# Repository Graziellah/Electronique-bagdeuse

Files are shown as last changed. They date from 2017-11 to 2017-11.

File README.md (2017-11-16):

# 42-electrons

Electronic project, group repertory

## Project specifications list

- [ ] A project name

- [ ] A project introduction

- [ ] A block diagram who's showing all the needed elements
    - [ ] At center the PIC32 chip
    - [ ] On borders the connectors
    - [ ] Between them, what is connected to what, how, and with what protocol

- [ ] A previsionnal manual who explain how to use
    - [ ] A final user must know how to use the final product

- [ ] Product specifications
    - [ ] Showing module (2 lines * 16 chars)
    - [ ] Memory
    - [ ] ...

- [ ] Functionnal calculations who explains the technical choices

- [ ] A list of protocols who will be used
    - [ ] How they will be used
    - [ ] How are they usefull
    - [ ] RFC
    - [ ] Implementation
    - [ ] Limitations

- [ ] A bill of materials
    - [ ] Components list
        - [ ] Compatibility
            - [ ] Interface
            - [ ] Packaging
            - [ ] Volts/Current
        - [ ] Datasheet
        - [ ] Builder reference
        - [ ] Farnell reference

- [ ] Example schematics of implementation of chosen components
    - [ ] Example diagrams instead if we don't know how to implement

### Protips

- We must use a PIC32 microcontroller of Microchip, no exceptions
- The only providers of school are Farnell & Olimex, the other must be paid with our own money
- The school take in charge PCBs and components (POC and prototypes) but not the "on sides" like Rasps, SD cards...

## Goals

- Lire des tags.
    - Autorisé
        - Sortie sur l'ecran
            - Granted
        - Action sur le relais
        - LED verte.
    - Refusé
        - Sortie sur l'écran
            - Refused
        - Buzz.
        - LED rouge.
- Ajouter/Supprimer des tags. (Via un ou plusieurs tags ***maitre*** / Port série)
    - Ajout
        - Sorties sur l'ecran
            - Temps d'Ajout
            - Confirmation
    - Suppression
        - Sorties sur l'ecran
            - Temps de suppression
            - Confirmation
    - Tag de maintenance
        - Sorties sur l'ecran
            - Statistiques
                - Slots restants
                - Uptime

### Obligatoire

- Proof of concept
    - Un lecteur RFID
    - Un écran
- Projet complet
    - Un port série
    - Un relai électrique

### Facultatifs (Bonus)

- Gestion du bluetooth
- Gestion de la stack IP
- Power Over Ethernet (Passif)
- Power Over Ethernet (Actif) # OP

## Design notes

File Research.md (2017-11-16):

# Reference list

- Microchip
    - [ ] Dependancies
        - RFID reader
        - LCD Screen
    - [ ] Memory (KBs)
        - Tags address ((16 x 8) bytes)
            - 12 standard UID
            - 4 maintainers UID
        - Firmware (32 KiloBytes)
    - [ ] Speed (MHz)
        - /
    - [ ] Architecture (Bits)
    - [ ] CPU (Type)
    - [ ] Core (Type)
    - [ ] RAM (Bytes)
    - [ ] Auxilliary flash (KBs)
    - [ ] Temperature range
    - [ ] Operation voltage range
    - [ ] DMA channel
    - [ ] A/D channel
    - [ ] Max A/D resolution (Bits)
    - [ ] USB
    - [ ] Comparators
    - [ ] Timers
    - [ ] Protocols (UART/SPI/I2C)
    - [ ] Codec interface (I25,AC97)
    - [ ] Peripheral Pins Select (PPS) Crossbar
    - [ ] EMI
    - [ ] SQI
    - [ ] Crypto Engine
    - [ ] CTMU
    - [ ] CAN modules
    - [ ] Type of CAN module
    - [ ] Ethernet
    - [ ] Pin count
    - [ ] Packages

- [ ] How to determine the MicroController needed
    - [ ] Determine the MicroController needed

- [ ] What are the specifications of the project
    - [ ] RFID specifications
        - [ ] Tags
            - [ ] 8 Bytes UID
        - [ ] Reader
    - [ ] Use the Gregoire's reference to determine what protocol to use

- [ ] Protocol list
    - [ ] RFID
        - [ ] Wiegand
    - [ ] LCD Screen interface
        - [ ] UART

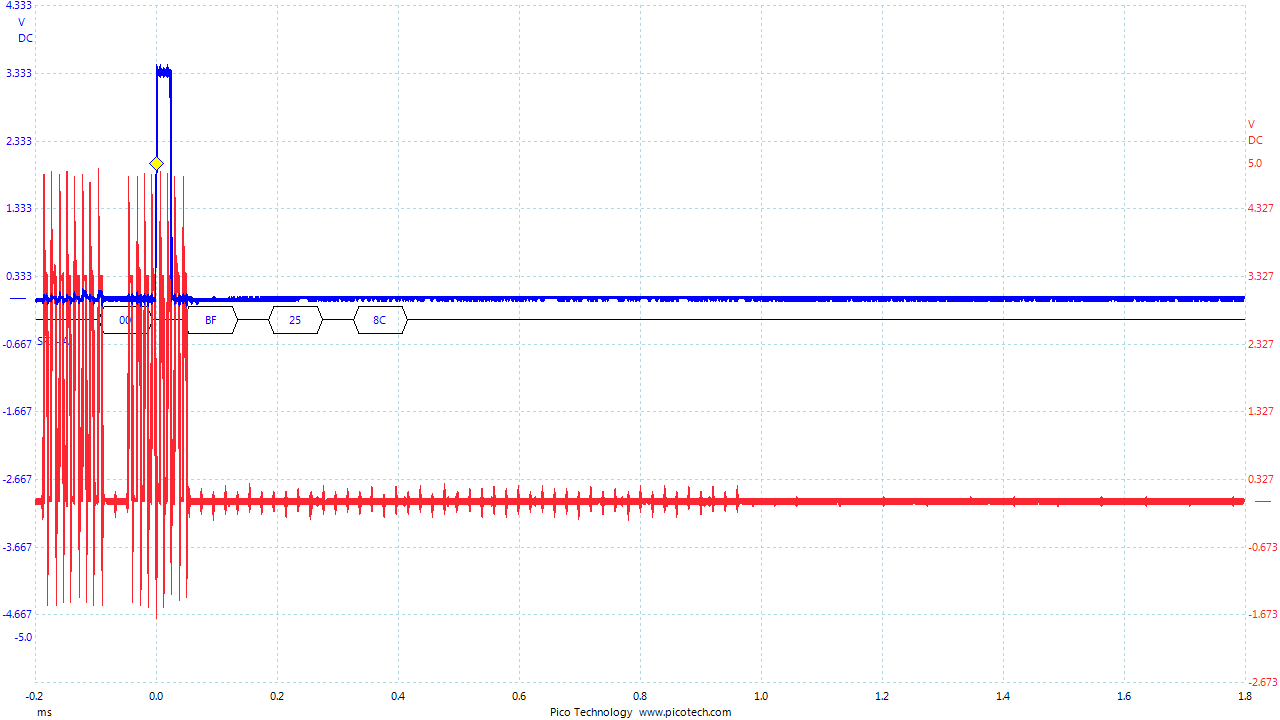
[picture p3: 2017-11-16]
pico/spi/spi_1.png

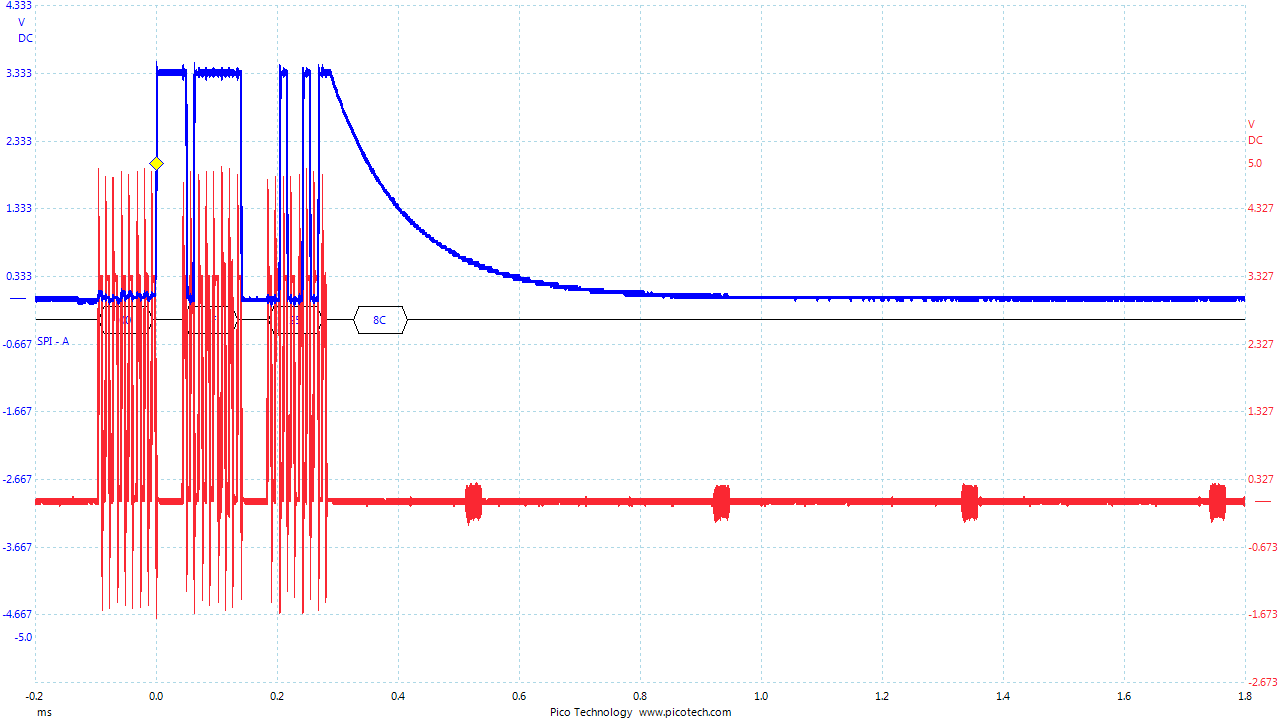
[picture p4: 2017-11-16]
pico/spi/spi_2.png

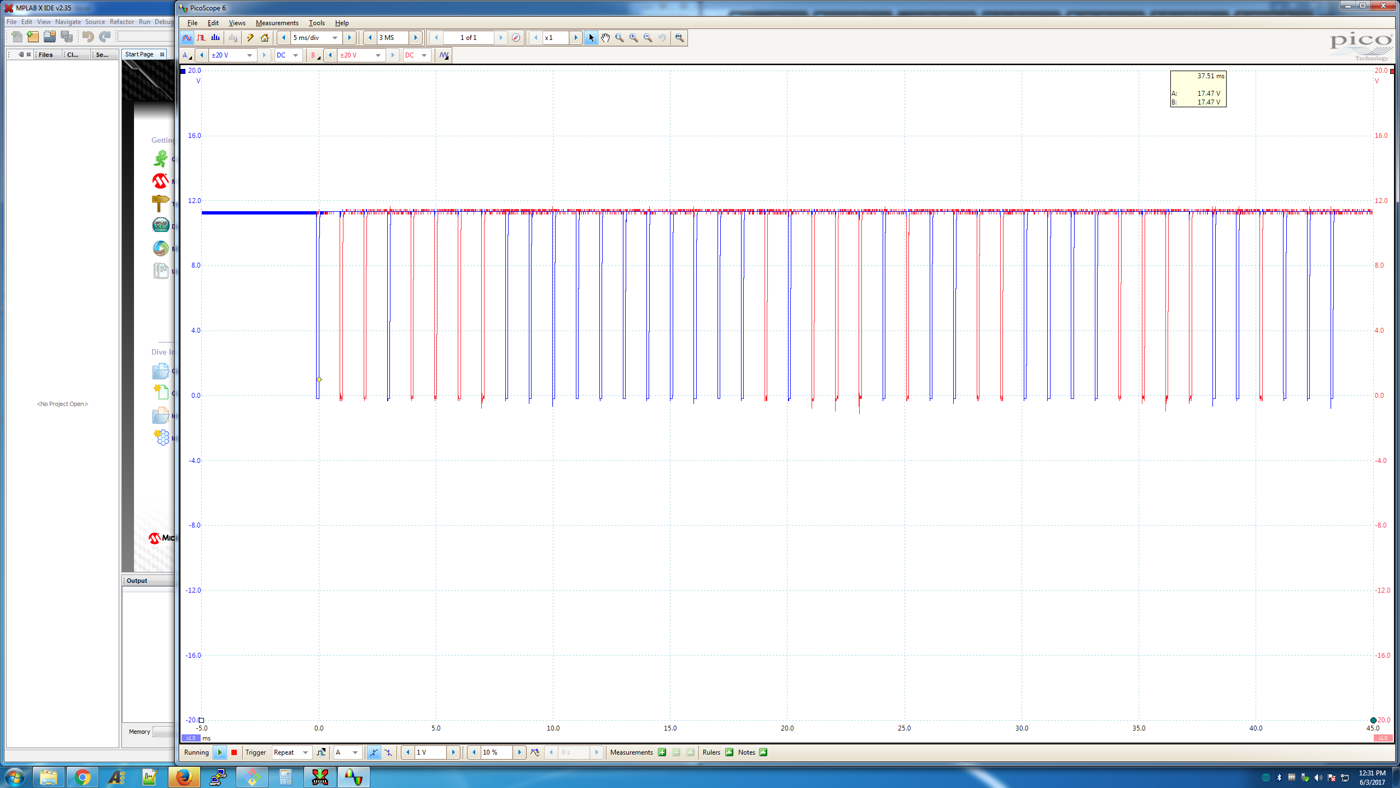
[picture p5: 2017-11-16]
tags/antho.png

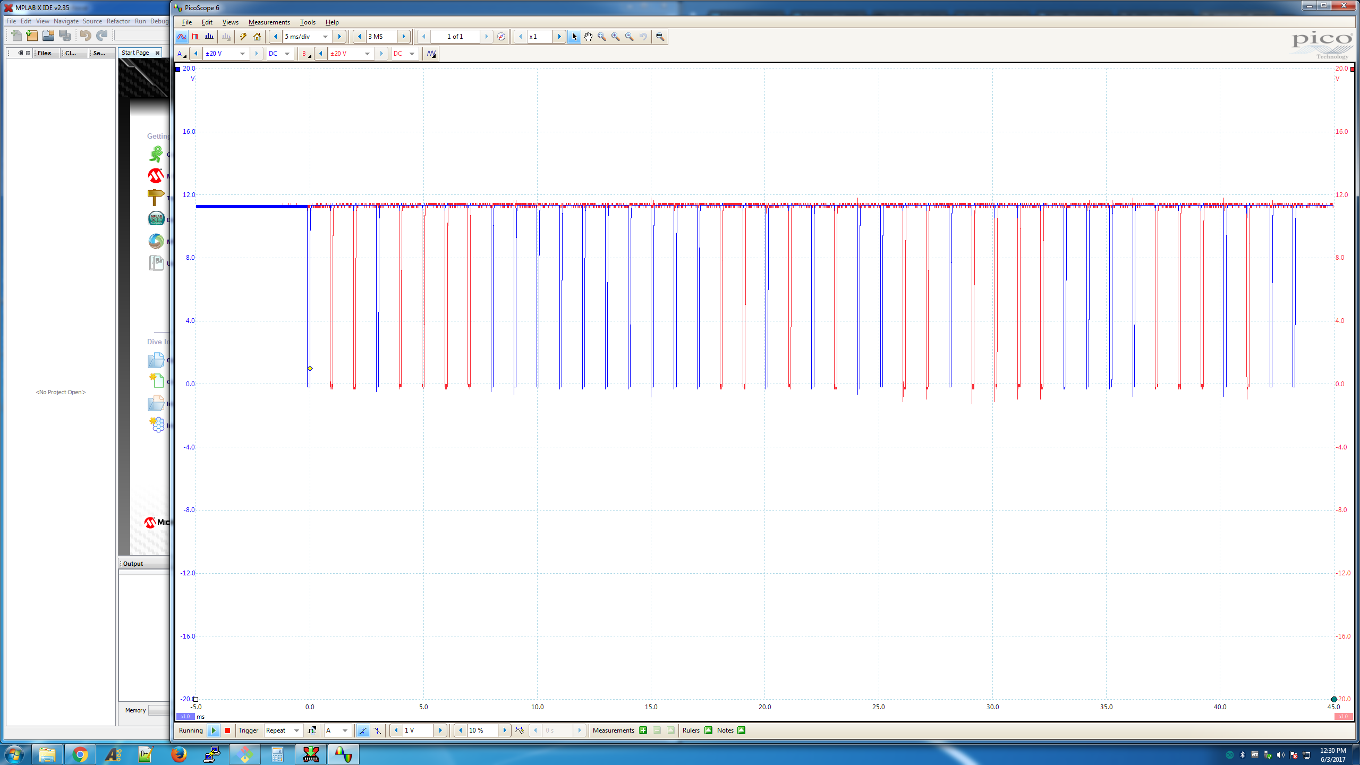
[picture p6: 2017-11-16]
tags/seb.png

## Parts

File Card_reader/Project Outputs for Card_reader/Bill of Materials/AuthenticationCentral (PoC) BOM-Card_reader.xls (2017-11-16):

BILL OF MATERIALS
Projet : |  | Card_reader.PrjPcb |  |  | Toutes résistances 1% sauf indication contraire
Date creation : |  | 28/01/2015 | 17:28:42 |  | Tous condensateurs X5R 6.3V minimum sauf indication contraire
Date impression : |  | 2017-06-20 | 14:09:08 |  | Condensateurs <= 100nF : C0G ou NP0 préférables
Quantity | Designator | Comment | Footprint | Description | Fabricant | RefFabricant | Fournisseur | RefFournisseur
1 | C5 | 10uF | CAP 0603 | Capacitor | TDK | C2012X5R0J106M/1.25 | Farnell | 2309029
2 | D3, D4 | GF1A | SMA/DO-214AC_21 | Default Diode | VISHAY | GF1A-E3/67A | Farnell | 9549560
1 | j3 | Bornier 2 pin | Bornier 2 pin |  | PHOENIX CONTACT | 1725656 | Farnell | 3041359
1 | J2 | Serial | Header 6 pin | Header 6 pin
3 | Q1, Q2, Q3 | 2N7002 | TO-236AB | Transistor MOSFET, Canal N, 300 mA, 60 V, 2.8 ohm, 10 V, 2 V | NEXPERIA | 2N7002,215 | Farnell | 1510761
1 | R3 | 28K | RES 0603 | Resistor | VISHAY | CRCW040228K0FKED | Farnell | 2140888
1 | R14 | 8.45K | RES 0603 | Resistor | VISHAY | CRCW04028K45FKED | Farnell | 2140852
1 | U1 | FDCC1602L-NSWBBW-91LE | LCD (Only header) |  | FORDATA | FDCC1602L-NSWBBW-91LE | Farnell | 1847941
1 | U2 | PIC32MX220F032B | SOIC (28) |  | MICROCHIP |  | Farnell
1 | U3 | LXM-R11_1 | Bornier 6 pin | Lecteur RFid | STid | LXM-R11
1 | U4 | LMR16006 | SOT (6) | Régulateurs à découpage DC/DC ajustables | Texas Instruments | LMR16006YDDC | Farnell | 2455134
1 | U5 | Relay | Relay | Relais de puissance | TE CONNECTIVITY / OEG | PCFN-112H2MS | Farnell | 2504686
1 | U6 | SST26VF032B-104I/SM | SOIC 8 |  | MICROCHIP | SST26VF032B-104I/SM | Farnell | 2471177

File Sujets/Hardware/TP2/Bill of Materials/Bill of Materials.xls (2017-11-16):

BILL OF MATERIALS
Projet : |  | TP2.PrjPcb |  |  | Toutes résistances 1% sauf indication contraire
Date creation : |  | 28/01/2015 | 17:28:42 |  | Tous condensateurs X5R 6.3V minimum sauf indication contraire
Date impression : |  | 2015-01-28 | 17:28:44 |  | Condensateurs <= 100nF : C0G ou NP0 préférables
Quantity | LogicalDesignator | Comment | Footprint | Description | Fabricant | RefFabricant | Fournisseur | RefFournisseur | Precision | #Column Name Error:Notes
7 | C1, C2, C3, C4, C5, C6, C15 | 100nF | CAPC1608N | Capacitor |  |  |  |  | 50V X5R
2 | C7, C8 | 20pF | CAPC1005N | Capacitor |  |  |  |  | 50V X5R
4 | C9, C11, C12, C13 | 10uF | CAPC2012N | Capacitor | TDK | C2012X5R0J106M/1.25 | Farnell | 2309029 | 6,3V X5R
2 | C10, C14 | 1uF | CAPC1608N | Capacitor |  |  |  |  | 6,3V X5R
5 | D1, D1, D1, D1, D4 | Green LED | LED 0805 | Typical INFRARED GaAs LED | KINGBRIGHT | KPT-2012SGC | Farnell | 2099239
2 | D2, D3 | GF1A | SMA/DO-214AC_21 | Default Diode | VISHAY | GF1A-E3/67A | Farnell | 9549560
1 | FB1 | 600r | INDC1608AN | Inductor | Wurth | 742792651 | Farnell | 1635706
1 | J1 | Program / Debug | MOLEX 6P 1.25 CMS |  | Molex | 53398-0671 | Farnell | 1125368
1 | P1 | 12V Main | PHOENIX_1985195 | Header, 2-Pin | PHOENIX CONTACT | PTSA 1.5/2-3,5-Z | Farnell | 1792769
1 | P2 | 12V Battery | PHOENIX_1985195 | Header, 2-Pin | PHOENIX CONTACT | PTSA 1.5/2-3,5-Z | Farnell | 1792769
1 | R1 | 1K | PDB181-K415K-102A2 | Potentiometer | BOURNS | PDB181-K415K-102A2 | Farnell | 1823540
4 | R2 | 330r | RESC1608N | Resistor |  |  |  |  | 1%
1 | R3 | 4.7k | RESC1608N | Resistor |  |  |  |  | 1%
1 | R4 | 470r | RESC1608N | Resistor |  |  |  |  | 1%
1 | U1 | PIC32MX764F128H-I/PT | QFP50P1200X1200X120-64 | PIC32MX764F128H | Microchip | PIC32MX764F128H-I/PT | Farnell | 1971889
1 | U2 | AP1117 | TD03B_N | 1A LDO, 18V input, DPAK | DIODES INC | AP1117D33G-13 | Farnell | 1825285
1 | Y1 | 8MHz | XTAL139X50X45 | Crystal Oscillator | FOX ELECTRONICS | FOXSDLF/080-20 | Farnell | 2063972

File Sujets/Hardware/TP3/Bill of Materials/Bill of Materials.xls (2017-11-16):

BILL OF MATERIALS
Projet : |  | TP3.PrjPcb |  |  | Toutes résistances 1% sauf indication contraire
Date creation : |  | 28/01/2015 | 17:45:48 |  | Tous condensateurs X5R 6.3V minimum sauf indication contraire
Date impression : |  | 2015-01-28 | 17:45:50 |  | Condensateurs <= 100nF : C0G ou NP0 préférables
Quantity | LogicalDesignator | Comment | Footprint | Description | Fabricant | RefFabricant | Fournisseur | RefFournisseur | Precision | #Column Name Error:Notes
7 | C1, C2, C3, C4, C5, C6, C15 | 100nF | CAPC1608N | Capacitor |  |  |  |  | 50V X5R
2 | C7, C8 | 20pF | CAPC1608N | Capacitor |  |  |  |  | 50V X5R
4 | C9, C11, C12, C13 | 10uF 6.3V | CAPC2012N | Capacitor | TDK | C2012X5R0J106M/1.25 | Farnell | 2309029 | 6,3V X5R
2 | C10, C14 | 1uF 6.3V | CAPC1608N | Capacitor |  |  |  |  | 6.3V X5R
5 | D1, D1, D1, D1, D4 | Green LED | LED 0805 | Typical INFRARED GaAs LED | KINGBRIGHT | KPT-2012SGC | Farnell | 2099239
2 | D2, D3 | GF1A | SMA/DO-214AC_21 | Default Diode | VISHAY | GF1A-E3/67A | Farnell | 9549560
1 | FB1 | 600r | INDC1608AN | Ferrite Bead | Wurth | 742792651 | Farnell | 1635706
1 | J1 | Program / Debug | RJ12_90 | RJ11 | Tyco | 1-215876-3 | Farnell | 1773039
1 | P1 | 12V Main | PHOENIX_1985195 | Header, 2-Pin | PHOENIX CONTACT | PTSA 1.5/2-3,5-Z | Farnell | 1792769
1 | P2 | 12V Battery | PHOENIX_1985195 | Header, 2-Pin | PHOENIX CONTACT | PTSA 1.5/2-3,5-Z | Farnell | 1792769
1 | R1 | 1K | PDB181-K415K-102A2 | Potentiometer | BOURNS | PDB181-K415K-102A2 | Farnell | 1823540
4 | R2 | 330r | RESC1608N | Resistor |  |  |  |  | 1%
1 | R3 | 4.7k | RESC1608N | Resistor |  |  |  |  | 1%
1 | R4 | 470r | RESC1608N | Resistor |  |  |  |  | 1%
1 | U1 | PIC32MX764F128H-I/PT | QFP50P1200X1200X120-64 | PIC32MX764F128H | Microchip | PIC32MX764F128H-I/PT | Farnell | 1971889
1 | U2 | AP1117 | TD03B_N | 1A LDO, 18V input, DPAK | DIODES INC | AP1117D33G-13 | Farnell | 1825285
1 | Y1 | 8MHz | HC49/4H SMX CRYSTAL | Crystal Oscillator | FOX ELECTRONICS | FOXSDLF/080-20 | Farnell | 2063972

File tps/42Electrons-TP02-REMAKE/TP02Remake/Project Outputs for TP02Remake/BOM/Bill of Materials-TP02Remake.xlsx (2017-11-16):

Comment | Description | Designator | Footprint | LibRef | Quantity
100nF | Capacitor | C1, C2, C3, C4, C5, C6, C15 | CAPC1608N | Cap | 7
20pF | Capacitor | C7, C8 | CAPC1005N | Cap | 2
10uF | Capacitor | C9, C11, C12, C13 | CAPC2012N | Cap | 4
1uF | Capacitor | C10, C14 | CAPC1608N | Cap | 2
Green LED | Typical INFRARED GaAs LED | D1_LED0, D1_LED1, D1_LED2, D1_LED3, D4 | LED 0805 | LED2 | 5
GF1A | Default Diode | D2, D3 | SMA/DO-214AC_21 | Diode | 2
600r | Inductor | FB1 | INDC1608AN | Inductor | 1
Program / Debug |  | J1 |  | Program / Debug | 1
12V Main | Header, 2-Pin | P1 | PHOENIX_1985195 | Header 2 | 1
12V Battery | Header, 2-Pin | P2 | PHOENIX_1985195 | Header 2 | 1
1K | Potentiometer | R1 | PDB181-K415K-102A2 | RPot | 1
330r | Resistor | R2_LED0, R2_LED1, R2_LED2, R2_LED3 | RESC1608N | Res1 | 4
4.7k | Resistor | R3 | RESC1608N | Res1 | 1
470r | Resistor | R4 | RESC1608N | Res1 | 1
PIC32MX764F128H-I/PT | PIC32MX764F128H | U1 | QFP50P1200X1200X120-64 | PIC | 1
AP1117 | 1A LDO, 18V input, DPAK | U2 | TD03B_N | AP1117 | 1
8MHz | Crystal Oscillator | Y1 | XTAL139X50X45 | XTAL | 1

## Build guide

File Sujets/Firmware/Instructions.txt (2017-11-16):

Le TP se déroule en étapes, à faire valider à chaque fois :

0/ Boot from scratch

Créer un nouveau projet et y ajouter un nouveau .h contenant des typedefs pour :
- u8, u16 et u32
- s8, s16 et s32

1/ Commande de la LED par le bouton (a.k.a Hello World!)

Une pression sur le bouton allume la led
Une autre pression sur le bouton éteint la led

2/ Clignotement de la LED

La led clignotte au rythme d'un changement d'état par seconde (0.5Hz, 1s on/1s off).
Une pression sur le bouton multiplie par deux le rythme de clignotement. Arrivé à 8Hz, une pression sur le bouton remet le rythme à 0.5Hz.

La "séquence" sera donc : 0.5Hz, 1Hz, 2Hz, 4Hz, 8hZ, 0.5Hz, 1Hz, ...

Vous devez utiliser un timer pour régler la vitesse de clignotement

3/ Utilisation des interruptions

Votre code doit maintenant être "non bloquant", votre main loop ne doit contenir qu'un statement: clear watchdog
Le clignotement ainsi que la gestion du bouton doivent être fait dans une ISR.

4/ DIM de la LED (a.k.a pour-les-vrais-qui-en-ont-dans-le-slip-ou-le-string)

Votre code fait toujours la même chose, mais sur un appui long (>2s) la led passe en mode DIM, en 5s son intensité passe de 0 à 100% puis de 100% à 0% (et ainsi de suite)

Pour cela vous coderez en firmware un PWM sur la GPIO qui contrôle la LED.

5/ Ca y est, vous savez tout faire, elle est pas belle la vie ?

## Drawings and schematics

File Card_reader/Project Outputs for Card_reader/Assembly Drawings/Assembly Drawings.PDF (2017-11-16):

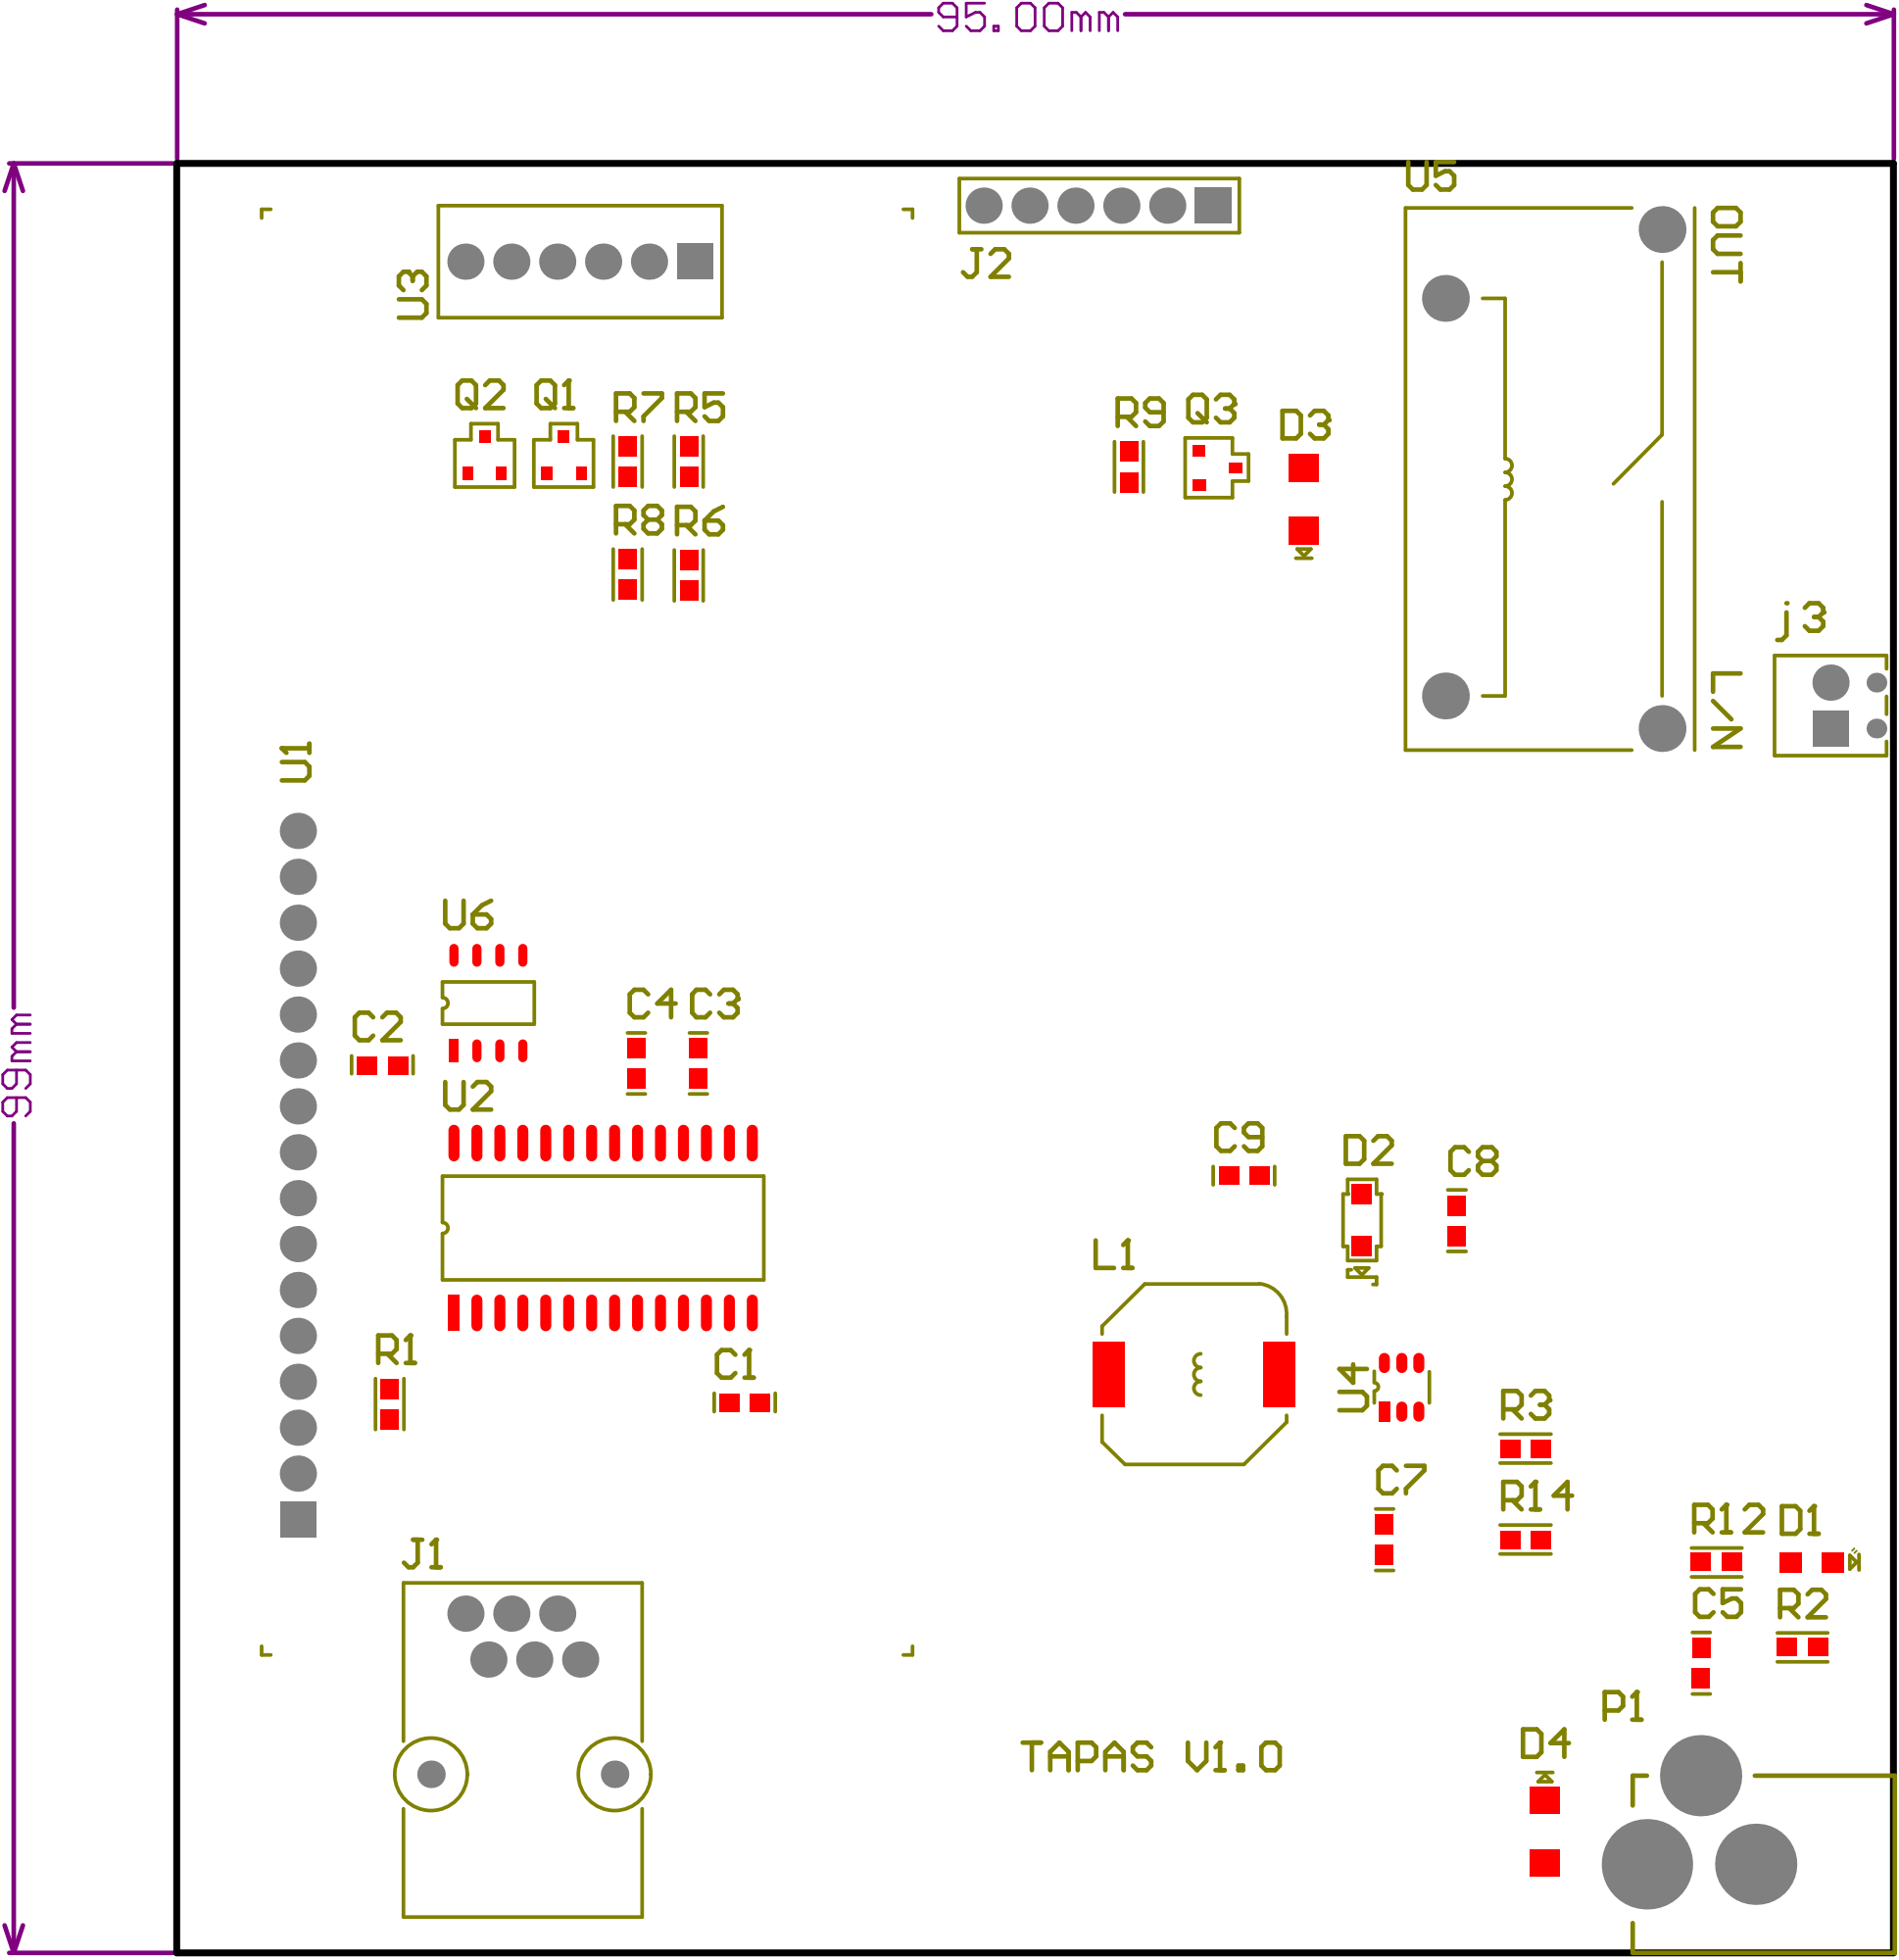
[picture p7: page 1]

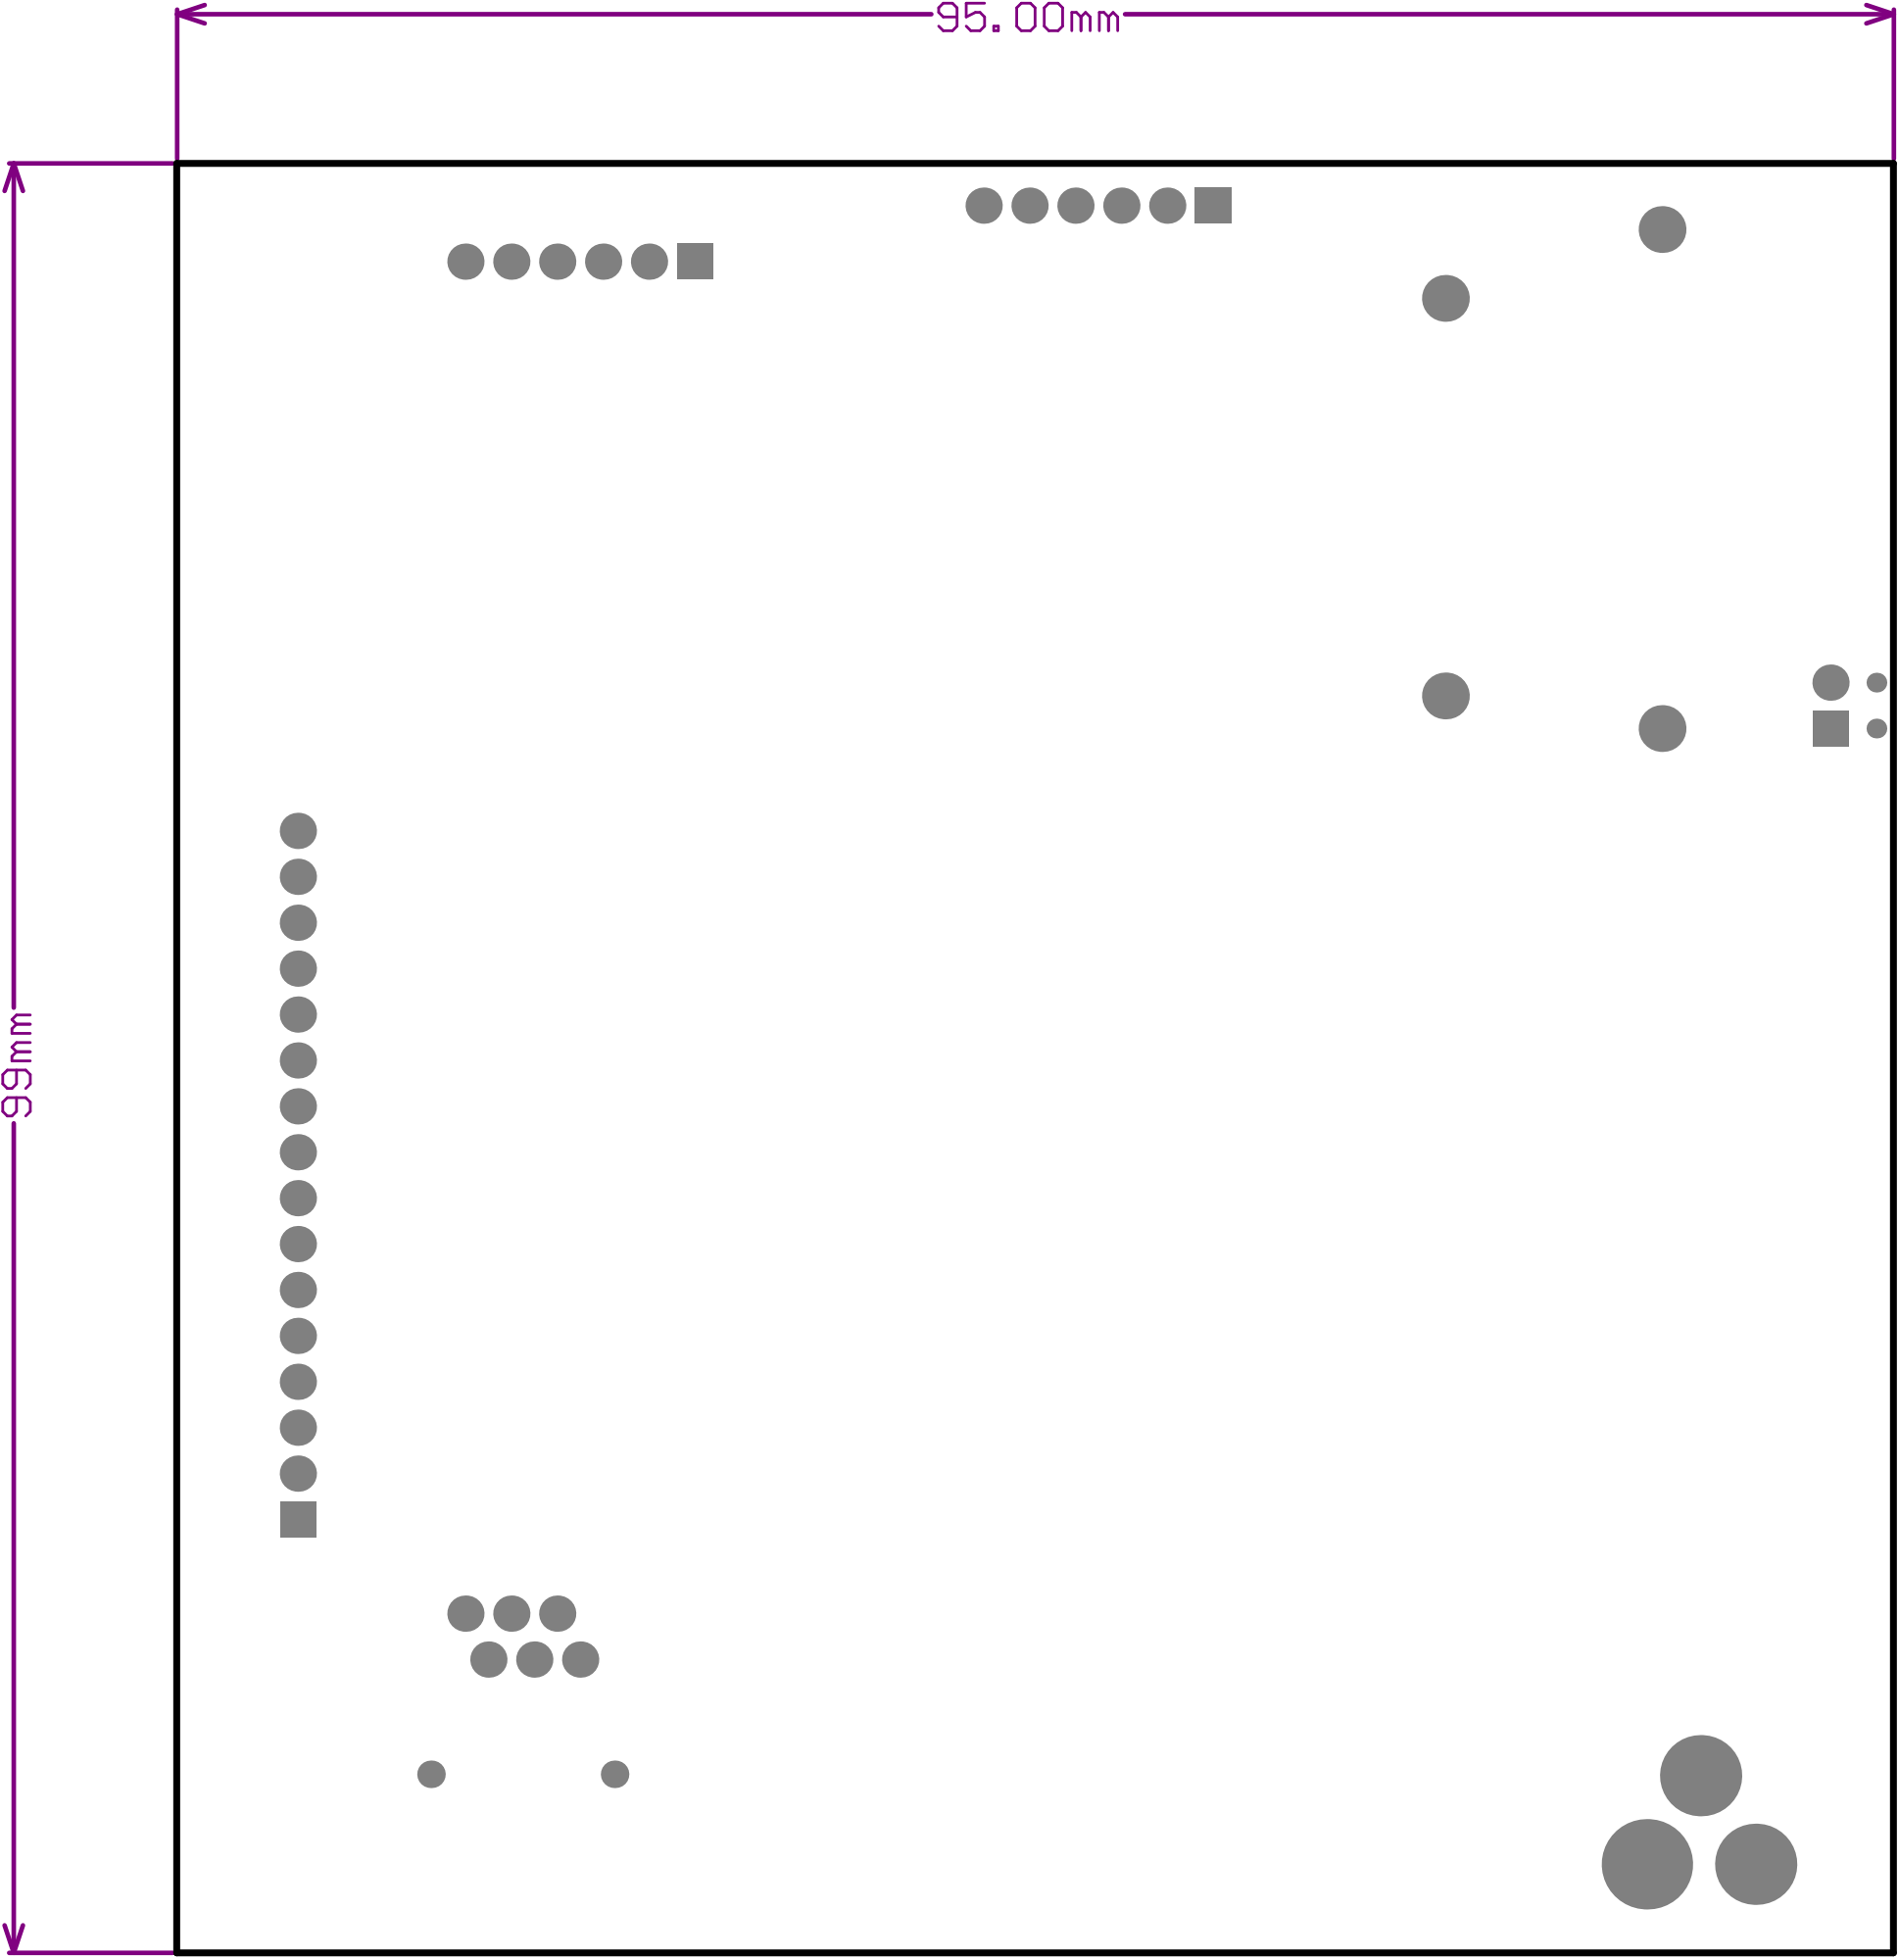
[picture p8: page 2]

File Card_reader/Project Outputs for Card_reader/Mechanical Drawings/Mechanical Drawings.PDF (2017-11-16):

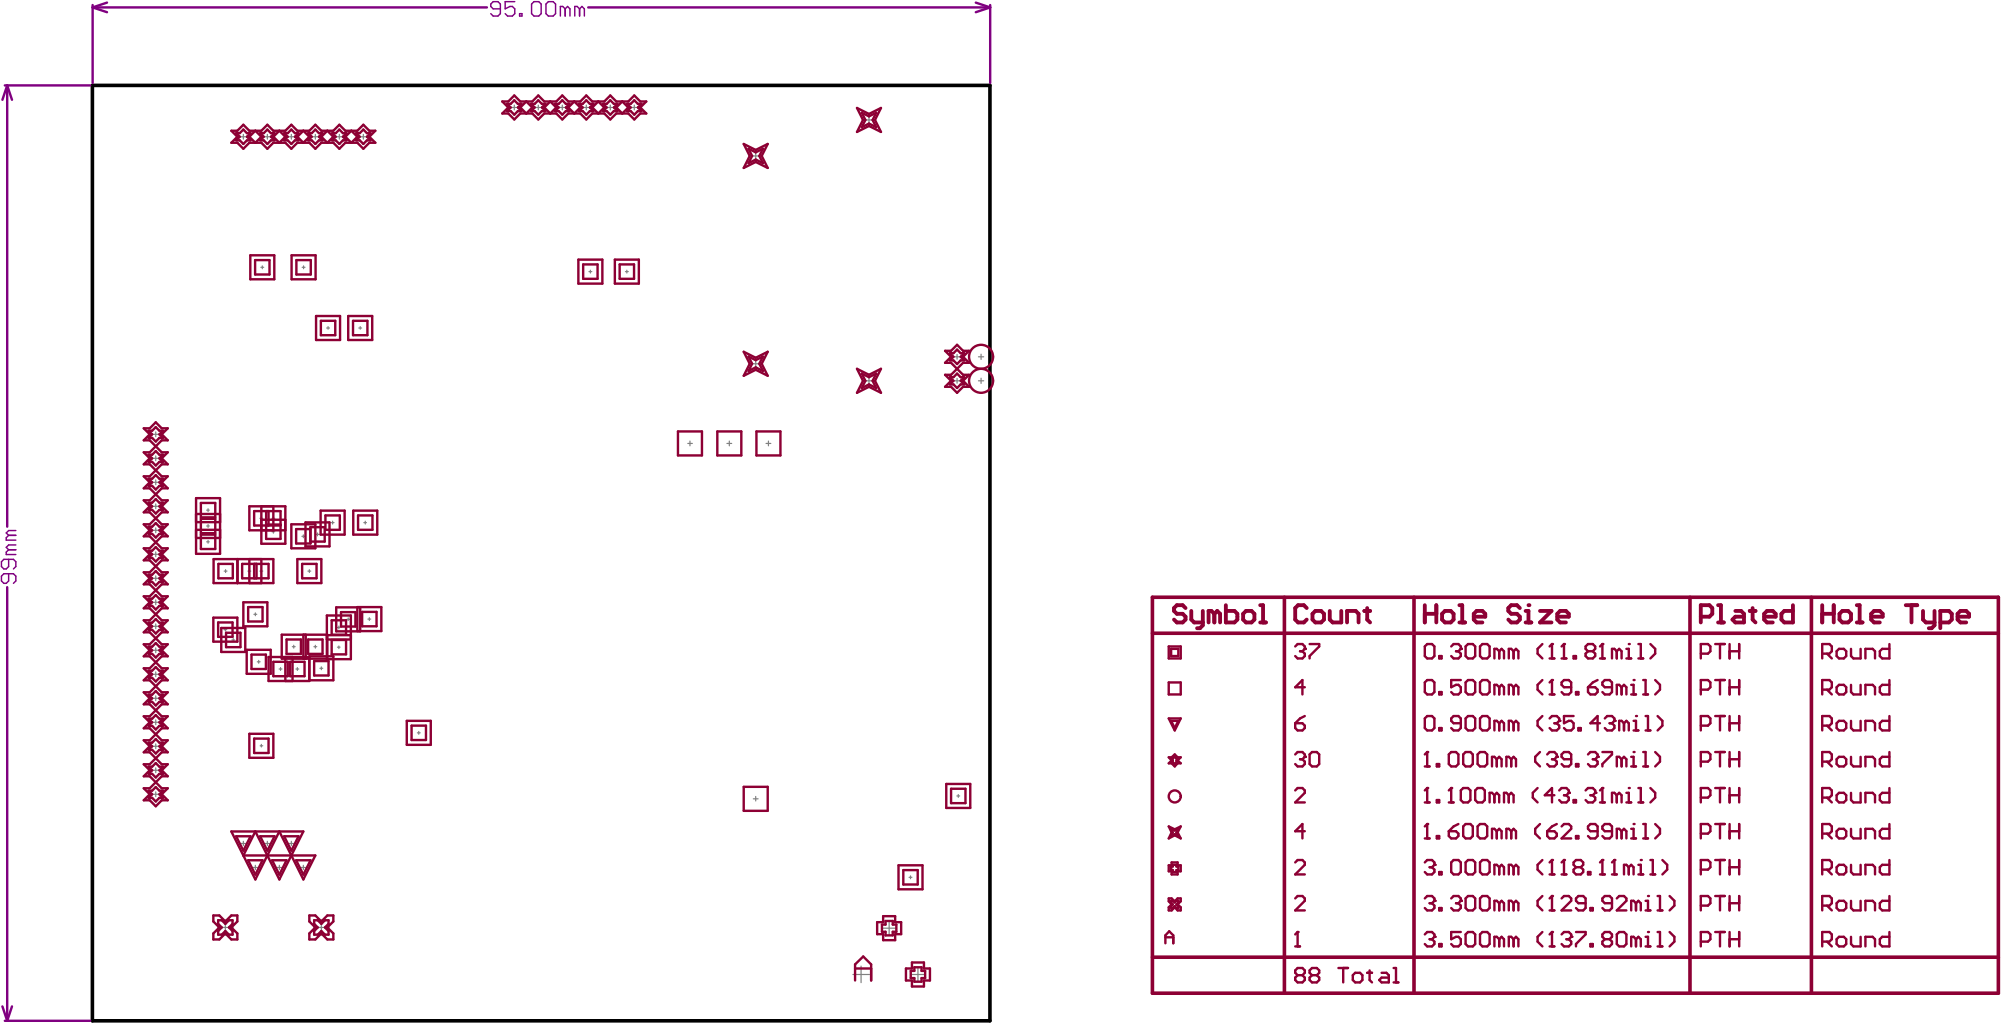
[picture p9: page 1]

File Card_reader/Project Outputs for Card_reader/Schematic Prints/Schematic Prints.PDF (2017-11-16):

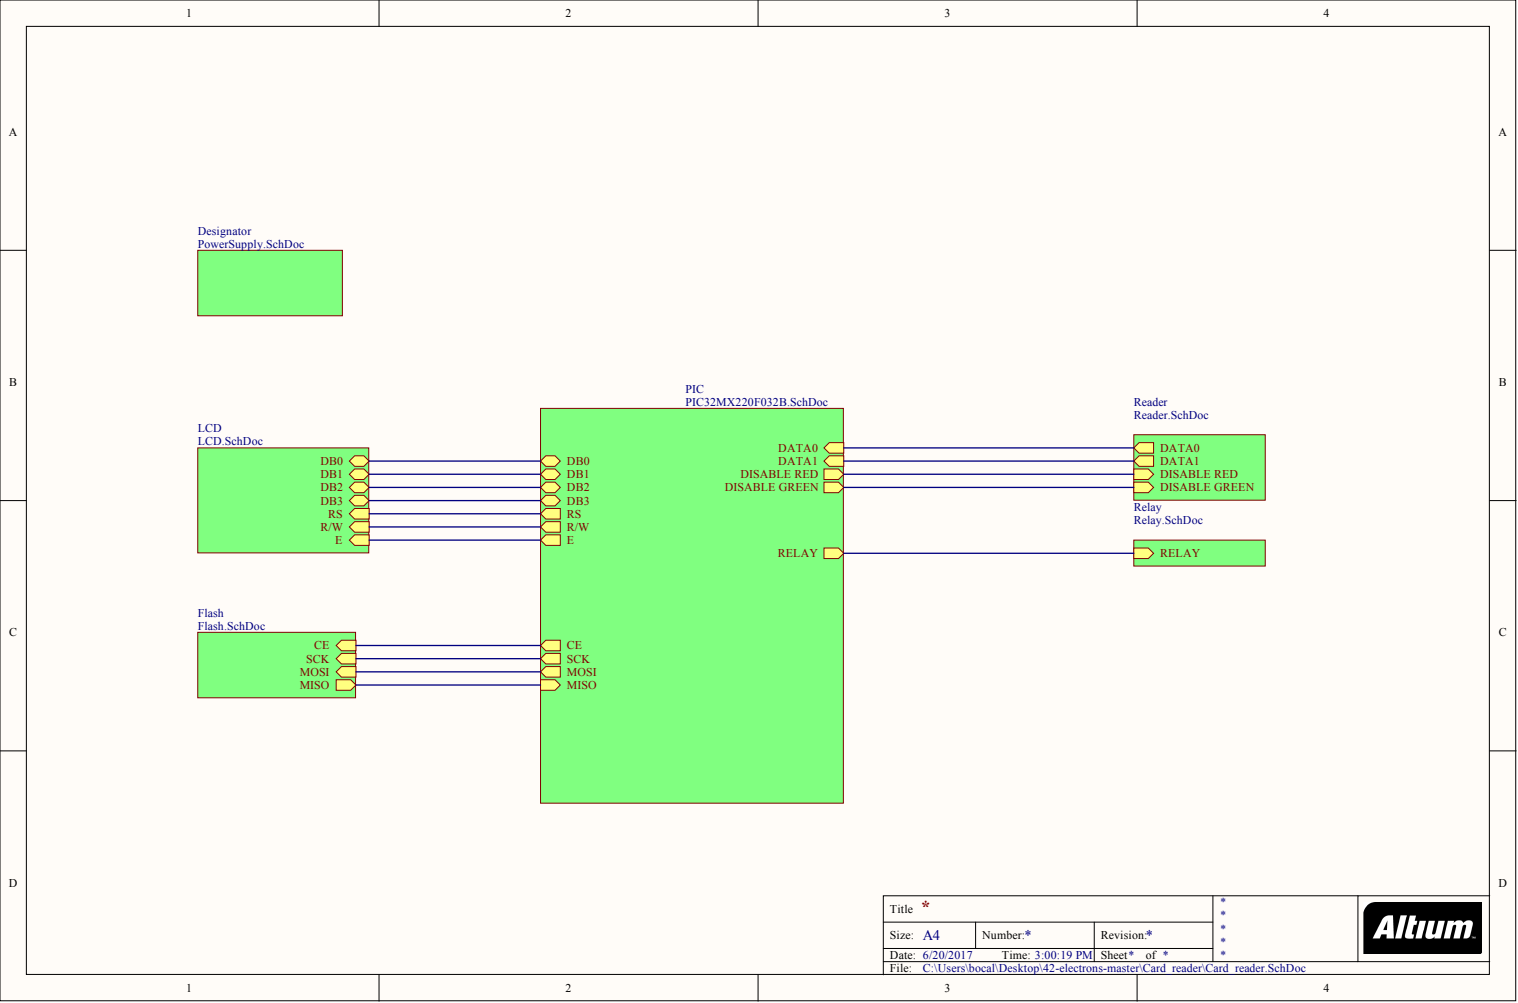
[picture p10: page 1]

Title * | * * *

Size: A4 | Number: | Revision:
Date: 6/20/2017 Time: 3:00:19 PM | | Sheet * of *

C:\Users\bocal\Desktop\42-electrons-master\Card_reader\Card_reader.SchDoc

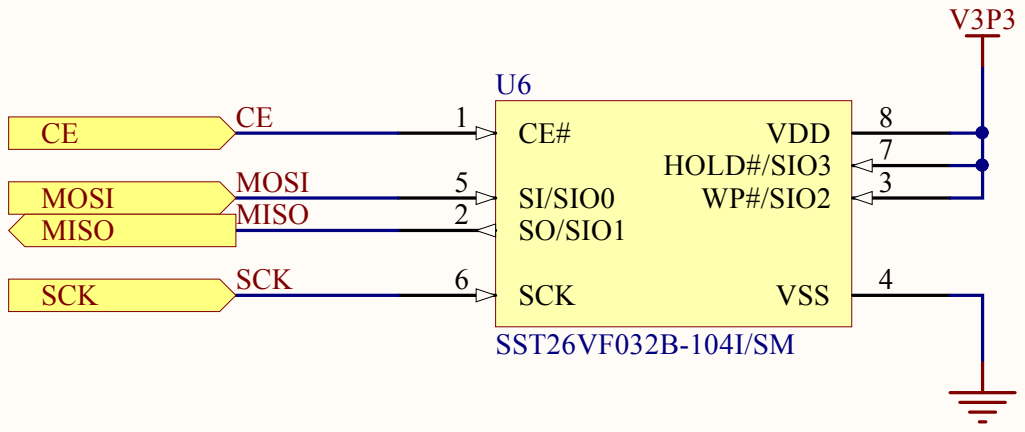
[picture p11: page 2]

Size: A | N umber: | Rev i s

/ T ime: : 9 PM | | Sheet f

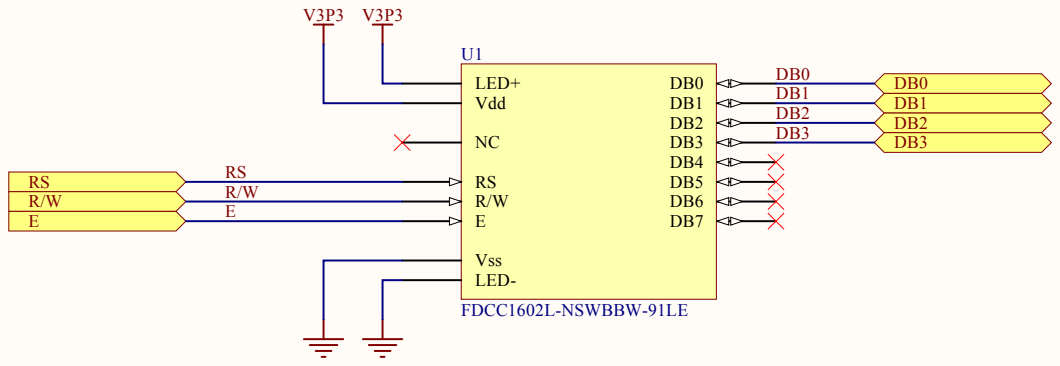
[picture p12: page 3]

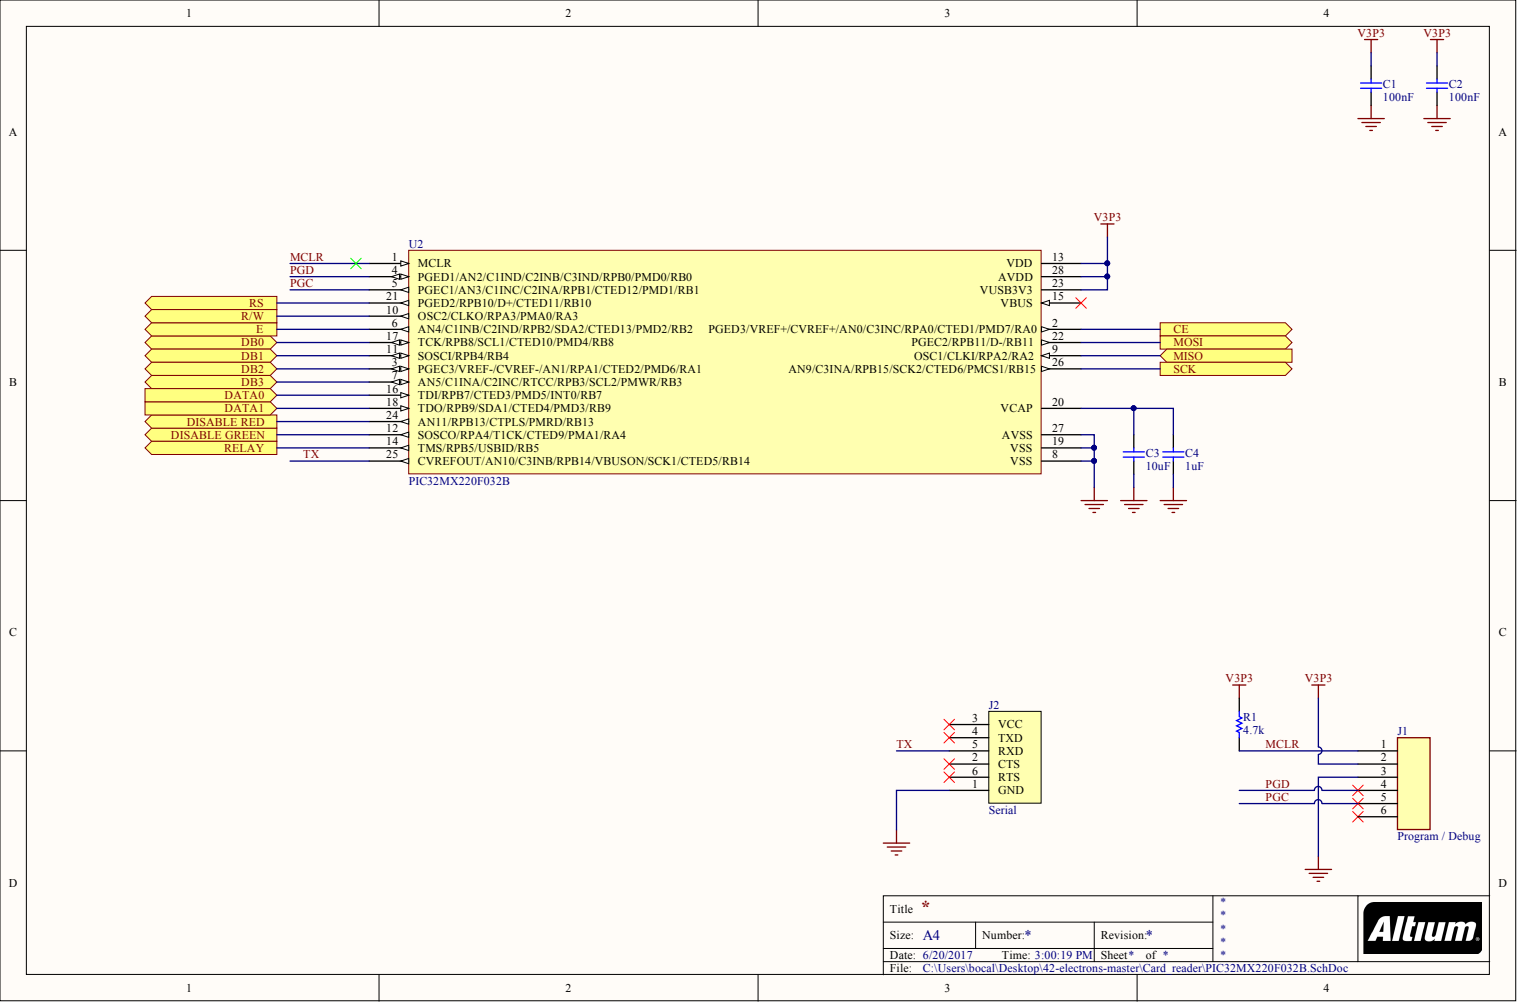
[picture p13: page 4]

C:\Users\bocal\Desktop\42-electrons-master\Card_reader\PIC32MX220F032B.SchDoc

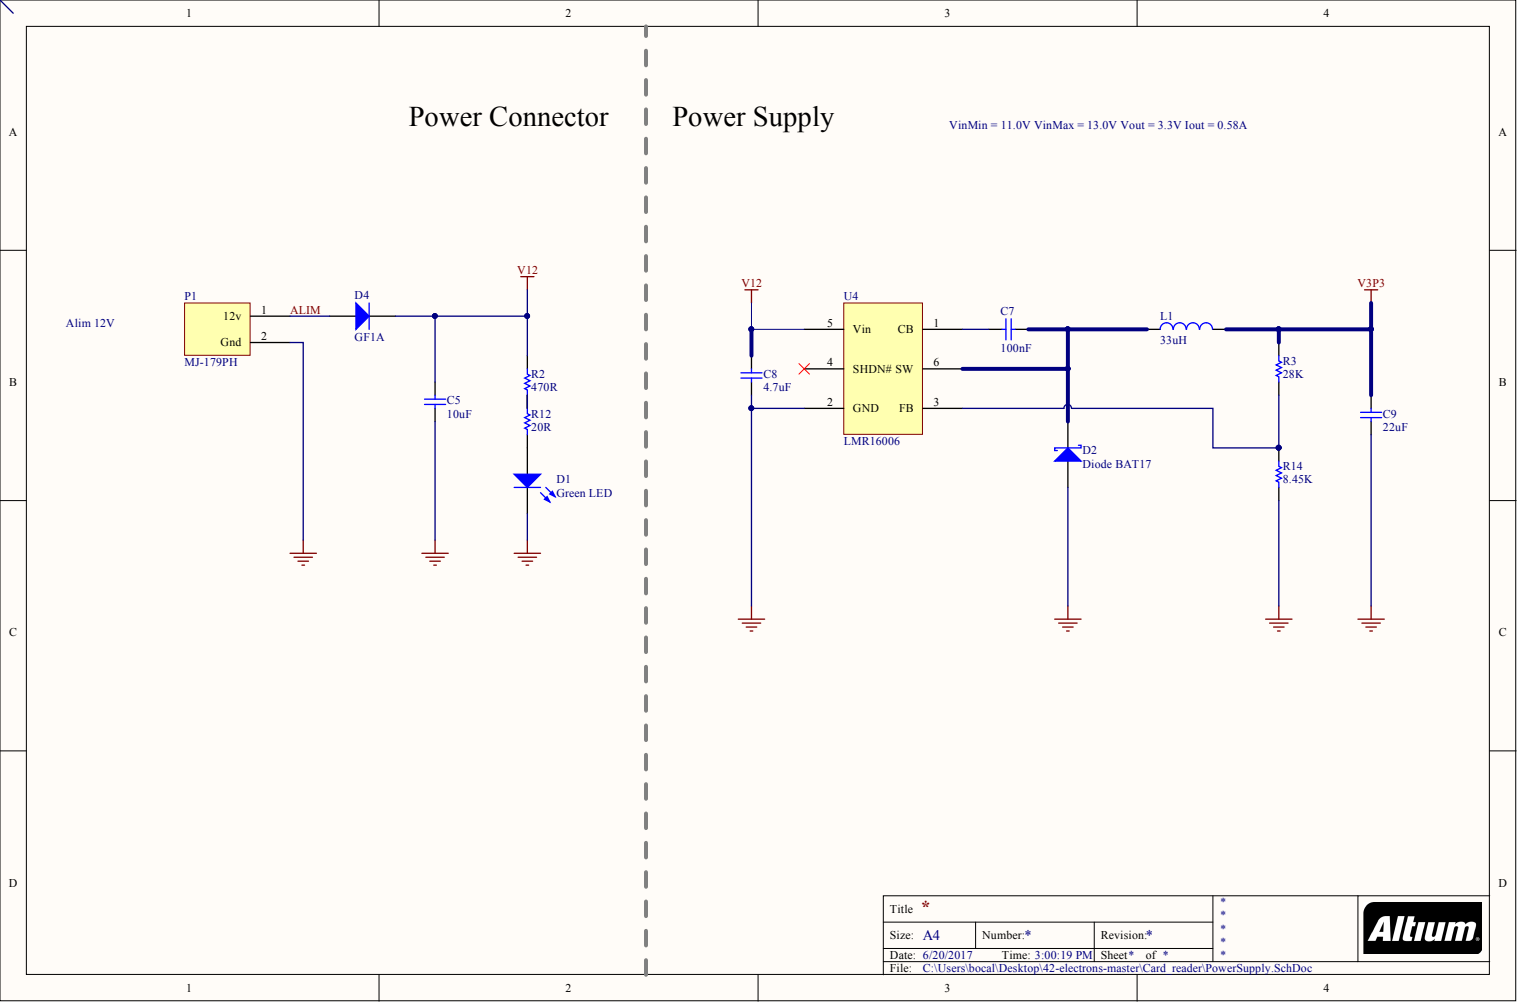
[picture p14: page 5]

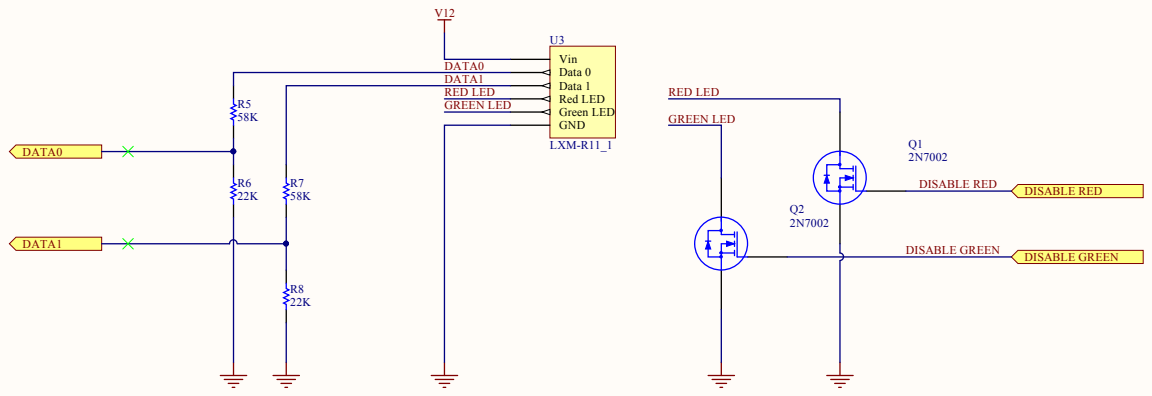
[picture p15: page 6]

D A T A 1
RE D L E D

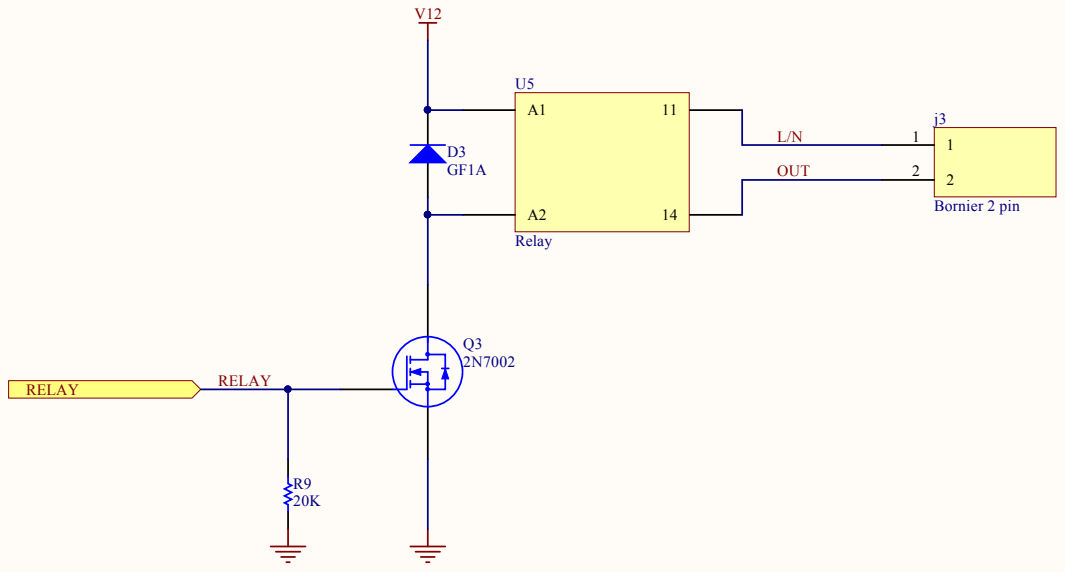
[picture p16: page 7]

C:\Users\bocal\Desktop\42-electrons-master\Card_reader\Relay.SchDoc

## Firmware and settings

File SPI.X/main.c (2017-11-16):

#include <sys/attribs.h>
#include <plib.h> // Microchip PIC32MX Peripheral Library

//Defines

#include <stdint.h>
#include <sys/attribs.h>
#include <proc/p32mx340f512h.h>

#define SYSCLK (8000000)
#define BAUDRATE (9600)
#define INPUT 1
#define OUTPUT 0
#define HIGH 1
#define LOW 0
#define INVERT_LED (LATFINV = 0b10)
#define LED_OFF (LATFbits.LATF1 = 0)
#define LED_ON (LATFbits.LATF1 = 1)

#define FLASH_CE LATGbits.LATG9 // Flash CE pin, SPI2CON SSEN = 0 donc le pin RG9 est controler par les port fonctions
#define FLASH_WP LATDbits.LATD0 // Write Protection is active low
#define FLASH_HOLD LATDbits.LATD1 // Hold is active low

// Typedefs
typedef unsigned char u8;
typedef unsigned int u16;
typedef unsigned long int u32;
typedef char s8;
typedef int s16;
typedef long int s32;


u8	strlen(u8 *str)
{
  u8 i = 0;
  while (str[i] != '\0')
    i++;
  return (i);
}



void init_IO()
{

    LED_OFF;
    TRISFbits.TRISF1 = OUTPUT;
    FLASH_CE = HIGH;
    TRISGbits.TRISG9 = OUTPUT; // FLASH CE pin
    FLASH_WP = HIGH;
    TRISDbits.TRISD0 = OUTPUT; // Flash WP pin
    FLASH_HOLD = HIGH;
    TRISDbits.TRISD1 = OUTPUT; // Flash HOLD pin

    TRISDbits.TRISD8 = INPUT; //Button
}


void    init_int()
{
    // Clear SPI2 Interrupt
    IEC1bits.SPI2EIE = 0;
    IEC1bits.SPI2RXIE = 0;
    IEC1bits.SPI2TXIE = 0;

    // Clear SPI2 Interrupt flag
    IFS1bits.SPI2EIF = 0;
    IFS1bits.SPI2RXIF = 0;
    IFS1bits.SPI2TXIF = 0;

    //ISR button
    IFS0bits.INT1IF = 0; //Unset the flag
    IEC0bits.INT1IE = 1; //Enable the button interrupt
    IPC1bits.INT1IP = 1; //Set the priority

    INTCONbits.MVEC = 1;
    __builtin_enable_interrupts();
}

void    init_SPI2()
{
        SPI2CON = 0; // stop and reset SPI2CON
        SPI2BUF = 0;
        SPI2BRG = 0; //set baudrate 2MHz
        SPI2CONbits.CKE = 1; // CKE: SPI Clock Edge Select bit 1 = Serial output data changes on transition from active clock state to idle clock state (see CKP bit) 0 = Serial output data changes on transition from idle clock state to active clock state (see CKP bit)
        SPI2CONbits.SMP = 0;
        SPI2CONbits.CKP = 0; // Clock Polarity Select bit 1 = Idle state for clock is a high level; active state is a low level 0 = Idle state for clock is a low level; active state is a high level
        SPI2CONbits.SSEN = 0;
        SPI2CONbits.MSTEN = 1; // Master Mode Enable bit
        //SPI2CONbits.MODE32 = 1; // mode 32bit
        SPI2CONbits.ON = 1; // enable SPI2
        SPI2BRG = 50;
}
void    init_UART2()
{
    U2STAbits.URXEN = 0; // Reciver Enable bit
    U2STAbits.UTXEN = 1; // Transmit Enable bit
    U2BRG = ((SYSCLK)/16/(BAUDRATE)-1);
    U2MODEbits.ON = 1;   // UART Enable bit
}

u32 SPI2_transmit32bits(u32 msg)
{
    //SPI2CONbits.MODE32 = 1;
    //FLASH_WP = HIGH;
    //FLASH_HOLD = HIGH;
    u32 res;

    //SPI2CONbits.MODE32 = 1;
    SPI2BUF = msg;
    FLASH_CE = LOW;

    while (!SPI2STATbits.SPIRBF) ;
    res = SPI2BUF;
    FLASH_CE = HIGH;
    return (res);
}

u32 SPI2_transmit8bits(u8 msg)
{
    u32 res;

    FLASH_CE = LOW;
    SPI2BUF = msg;
    while (!SPI2STATbits.SPIRBF);
    FLASH_CE = HIGH;
    res = SPI2BUF;

    return (res);
}

void      SPI2_read_RDSR()
{
    u8 res;

    u8 junk;

    FLASH_CE = LOW;
    SPI2BUF = 0x5;
    while (!SPI2STATbits.SPIRBF);
    res = SPI2BUF;

    SPI2BUF = junk;
    while (!SPI2STATbits.SPIRBF);
    res = SPI2BUF;

    FLASH_CE = HIGH;

}

void      SPI2_read_JEDEC()
{
    u8 res;
    
    u8 junk;

    FLASH_CE = LOW;
    SPI2BUF = 0x9f;
    while (!SPI2STATbits.SPIRBF);
    res = SPI2BUF;

    SPI2BUF = junk;
    while (!SPI2STATbits.SPIRBF);
    res = SPI2BUF;

    SPI2BUF = junk;
    while (!SPI2STATbits.SPIRBF);
    res = SPI2BUF;

    SPI2BUF = junk;
    while (!SPI2STATbits.SPIRBF);
    res = SPI2BUF;


    FLASH_CE = HIGH;

    //res = SPI2_transmit32bits(0x9f);
    //res = SPI2_transmit32bits(0x9f);
    //res = SPI2_transmit8bits(0x9f);
    //res = SPI2_transmit32bits(0b11111001);

    //res = SPI2_transmit32bits(0b11111001);
    //1001 1111
    //SPI2BUF = (0x9F);
    //SPI2BUF = (0b10100000111100001111101010011001);
}

u32      SPI2_readID()
{
    u8 res;
    //res = SPI2_transmit32bits(0x90);
    res = SPI2_transmit8bits(0x90);
    return (res);
}
/*
void    readFlashFromAddr(u32 addr)
{
    u8 read = 0b00000011;
    SPI2BUF = (addr << 8) | read;
    CE_ENABLE;
}
*/

void    writeCharUART2(const char c)
{
    while (U2STAbits.UTXBF); //or while(!U1STAbits.TRMT);
    U2TXREG = c;
}

void    writeStringUART2(const char* str)
{
    u8 i = 0;

    while(str[i])
    {
        while (U2STAbits.UTXBF); //or while(!U1STAbits.TRMT);
        U2TXREG = (str[i++]);
    }
}

void    writeDataUART2(u8 data)
{
    u8 i = 0;
    while(U2STAbits.UTXBF);
    while(i <= 8)
    {
        writeCharUART2(((data >> i++) & 0b1) + 48);
    }
}

int main()
{
     int pbClk;
    pbClk = SYSTEMConfigPerformance(SYSCLK);

    init_UART2();
    init_SPI2();
    init_int();
    init_IO();

    while (1)
    {
        WDTCONbits.WDTCLR = 1; //Pet the dog
    }
    return (0);
}

void __ISR(_EXTERNAL_1_VECTOR, IPL1AUTO) ButtonHandler(void)
{
    SPI2_read_JEDEC();
    //SPI2_read_RDSR();
    IFS0bits.INT1IF = 0;
}

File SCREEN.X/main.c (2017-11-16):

#include <sys/attribs.h>
#include <plib.h> // Microchip PIC32MX Peripheral Library

//Defines

#include <stdint.h>
#include <sys/attribs.h>
#include <proc/p32mx340f512h.h>

#define SYSCLK (8000000)
#define BAUDRATE (9600)
#define INPUT 1
#define OUTPUT 0
#define HIGH 1
#define LOW 0
#define INVERT_LED (LATFINV = 0b10)
#define LED_OFF (LATFbits.LATF1 = 0)
#define LED_ON (LATFbits.LATF1 = 1)
#define BUTTON_PRESSED (PORTD)

//Flash
#define FLASH_CE_ON (LATGbits.LATG9 = LOW); // Flash CE pin, SPI2CON SSEN = 0 donc le pin RG9 est controler par les port fonctions
#define FLASH_CE_OFF (LATGbits.LATG9 = HIGH);
#define FLASH_WP_ON (LATDbits.LATD0 = LOW) // write protection is active low
#define FLASH_WP_OFF (LATDbits.LATD0 = HIGH)
#define FLASH_HOLD_OFF (LATDbits.LATD1 = HIGH) // Hold is active low
#define FLASH_HOLD_ON (LATDbits.LATD1 = LOW)

//LCD
#define LCD_DB0 LATEbits.LATE0
#define LCD_DB1 LATEbits.LATE1
#define LCD_DB2 LATEbits.LATE2
#define LCD_DB3 LATEbits.LATE3
#define LCD_DB4 LATEbits.LATE4
#define LCD_DB5 LATEbits.LATE5
#define LCD_DB6 LATEbits.LATE6
#define LCD_DB7 LATEbits.LATE7
#define LCD_ENABLE LATDbits.LATD0
#define LCD_RS LATDbits.LATD1
#define LCD_RW LATDbits.LATD2

// Typedefs
typedef unsigned char u8;
typedef unsigned int u16;
typedef unsigned long int u32;
typedef char s8;
typedef int s16;
typedef long int s32;

void initIO()
{
    //LCD
    LCD_DB0 = LOW;
    LCD_DB1 = LOW;
    LCD_DB2 = LOW;
    LCD_DB3 = LOW;
    LCD_DB4 = LOW;
    LCD_DB5 = LOW;
    LCD_DB6 = LOW;
    LCD_DB7 = LOW;

    TRISEbits.TRISE0 = OUTPUT;
    TRISEbits.TRISE1 = OUTPUT;
    TRISEbits.TRISE2 = OUTPUT;
    TRISEbits.TRISE3 = OUTPUT;
    TRISEbits.TRISE4 = OUTPUT;
    TRISEbits.TRISE5 = OUTPUT;
    TRISEbits.TRISE6 = OUTPUT;
    TRISEbits.TRISE7 = OUTPUT;
    TRISDbits.TRISD1 = OUTPUT;
    TRISDbits.TRISD2 = OUTPUT;

    LCD_ENABLE = LOW;
    TRISDbits.TRISD0 = OUTPUT;

    LCD_RS = LOW;
    TRISDbits.TRISD1 = OUTPUT;

    LCD_RW = LOW;
    TRISDbits.TRISD2 = OUTPUT;
}

void    initInt()
{
    // Clear SPI2 Interrupt
    IEC1bits.SPI2EIE = 0;
    IEC1bits.SPI2RXIE = 0;
    IEC1bits.SPI2TXIE = 0;

    // Clear SPI2 Interrupt flag
    IFS1bits.SPI2EIF = 0;
    IFS1bits.SPI2RXIF = 0;
    IFS1bits.SPI2TXIF = 0;

    TRISDbits.TRISD8 = INPUT; //Button
    //ISR button
    IFS0bits.INT1IF = 0; //Unset the flag
    IEC0bits.INT1IE = 1; //Enable the button interrupt
    IPC1bits.INT1IP = 1; //Set the priority to 7

    INTCONbits.MVEC = 1;
    __builtin_enable_interrupts();
}

void    initUART2(int pbClk)
{
    U2MODEbits.ON = 1;   // UART Enable bit
    U2STAbits.URXEN = 0; // Reciver Enable bit
    U2STAbits.UTXEN = 1; // Transmit Enable bit
    U2BRG = ((pbClk)/16/(BAUDRATE)-1);
}

void    lcdRWMode(s8 enable)
{
    LCD_DB0 = LOW;
    LCD_DB1 = LOW;
    LCD_DB2 = LOW;
    LCD_DB3 = LOW;
    LCD_DB4 = LOW;
    LCD_DB5 = LOW;
    LCD_DB6 = LOW;
    LCD_DB7 = LOW;
    if (enable)
    {
        TRISEbits.TRISE0 = INPUT;
        TRISEbits.TRISE1 = INPUT;
        TRISEbits.TRISE2 = INPUT;
        TRISEbits.TRISE3 = INPUT;
        TRISEbits.TRISE4 = INPUT;
        TRISEbits.TRISE5 = INPUT;
        TRISEbits.TRISE6 = INPUT;
        TRISEbits.TRISE7 = INPUT;
        TRISDbits.TRISD1 = INPUT;
        TRISDbits.TRISD2 = INPUT;
    }
    else
    {
        TRISEbits.TRISE0 = OUTPUT;
        TRISEbits.TRISE1 = OUTPUT;
        TRISEbits.TRISE2 = OUTPUT;
        TRISEbits.TRISE3 = OUTPUT;
        TRISEbits.TRISE4 = OUTPUT;
        TRISEbits.TRISE5 = OUTPUT;
        TRISEbits.TRISE6 = OUTPUT;
        TRISEbits.TRISE7 = OUTPUT;
        TRISDbits.TRISD1 = OUTPUT;
        TRISDbits.TRISD2 = OUTPUT;
    }
}

void    clearLCD()
{
    LCD_RS = LOW;
    LCD_RW = LOW;

    LCD_DB0 = HIGH;
    LCD_DB1 = LOW;
    LCD_DB2 = LOW;
    LCD_DB3 = LOW;
    LCD_DB4 = LOW;
    LCD_DB5 = LOW;
    LCD_DB6 = LOW;
    LCD_DB7 = LOW;

    LCD_ENABLE = HIGH;
    while(lcdBusy());
    LCD_ENABLE = LOW;
}

u8      lcdBusy()
{
    u8 busy;

    lcdRWMode(1);
    LCD_RS = LOW;
    LCD_RW = HIGH;
    u8 busy = LCD_DB7;
    lcdRWMode(0);
    return (busy);
}

void    putcLCD(char c)
{
    LCD_DB0 = (c >> 0) & 0b1;
    LCD_DB1 = (c >> 1) & 0b1;
    LCD_DB2 = (c >> 2) & 0b1;
    LCD_DB3 = (c >> 3) & 0b1;
    LCD_DB4 = (c >> 4) & 0b1;
    LCD_DB5 = (c >> 5) & 0b1;
    LCD_DB6 = (c >> 6) & 0b1;
    LCD_DB7 = (c >> 7) & 0b1;

    while(lcdBusy());
    LCD_ENABLE = HIGH;
    while(lcdBusy());
    LCD_ENABLE = LOW;
}

void    putsLCD(char *str)
{
    u8 i = 0;
    while(str[i])
    {
        putcLCD(str[i++]);
    }
}

char    writeSPI(char data)
{
    SPI2BUF = data; // TX Data
    // wait until spi ready
    //SPI2STATbits.
    data = SPI2BUF;
    return (data);
}

u32      flashReadJEDEC()
{
    u8 junk;
    junk = SPI2BUF;
    FLASH_CE_OFF;
    SPI2BUF = (0x9F);
    while(SPI2STATbits.SPIBUSY);// wait until SPI is in idle mode
    FLASH_CE_ON;
    while(!SPI2STATbits.SPITBE); // wait until transmit buffer empty

    while(SPI2STATbits.SPIBUSY);// wait until SPI is in idle mode

    FLASH_CE_OFF;
   return (SPI2BUF);
}
/*
void    readFlashFromAddr(u32 addr)
{
    u8 read = 0b00000011;
    SPI2BUF = (addr << 8) | read;
    CE_ENABLE;
}
*/

void    writeStringUART2(const char* str)
{
    u8 i = 0;

    while(str[i])
    {
        while (U2STAbits.UTXBF); //or while(!U1STAbits.TRMT);
        U2TXREG = (str[i++]);
    }
}

void    writeDataUART2(u32 data)
{
    u8 i = 0;
    while (U2STAbits.UTXBF);
    U2TXREG = (data);
}

int main()
{
    int pbClk;
    pbClk = SYSTEMConfigPerformance(SYSCLK);

    initUART2(pbClk);
    initSPI2();
    initInt();
    initIO();

	while (1)
	{
		WDTCONbits.WDTCLR = 1; //Pet the dog
	}
	return (0);
}

void __ISR(_EXTERNAL_1_VECTOR, IPL1AUTO) ButtonHandler(void)
{
        u32 data = flashReadJEDEC();
        writeStringUART2("TEST\r\n");
        writeDataUART2(data);
        writeStringUART2("\r\n");
	IFS0bits.INT1IF = 0;
}
